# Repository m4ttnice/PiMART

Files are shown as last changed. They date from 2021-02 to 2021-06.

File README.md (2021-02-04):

# PiMART

## Introducción
Proyecto del equipo MART para la temporada 2020/2021 de Formula Student. Se pretende diseñar un sistema de telemetría basado en una Rasberry-Pi.

## Conceptos previos

El sistema debe poseer las siguientes características, ordenadas por prioridad:

1. [x] **RTC** (ds3231) para el RPI. La raspberry no tiene integrado reloj del sistema, para sistemas "aislados" se necesita añadir uno para tener un reloj sincronizado (dato indispensable para un sistema de telemetría). Utiliza bus i2c (0x68)
1. [x] Bus **i2c** en el **RPI** (pruebas con RTC (ds3231 0x68) y IMU (mpu6050 0x69))
1. [ ] (**WIP**) **i2c** para **C/C++** en la RPI (pruebas con RTC (ds3231) y IMU (mpu6050))
1. [ ] Capacidad de recepción/transmisión mediante bus **CAN**, para comunicación con la **ECU**.
1. [ ] **GPS** + **IMU** (proporcionados por TORSA) (DETERMINAR **MODELO y LIBRERÍAS** A UTILIZAR) (con un enlace al **datasheet** basta por ahora)
1. [ ] **RPI** definitiva (proporcionados por TORSA) (DETERMINAR **MODELO, SO y CARACTERÍSTICAS** A UTILIZAR)
1. [ ] Almacenamiento de datos recibidos por CAN desde ECU.
1. [ ] Leer, en la RPI, el estado de los *botones del volante* (18), se pueden usar 2 opciones:
    - **Lectura directa**: se cablea cada interruptor a un pin **GPIO** o a una entrada de **multiplexor** y este a GPIO (en ppio más simple en SOFTWARE, más complicado en HARWARE [ **MUCHOS** cables desde el volante al RPI])
    - **Lectura indirecta**: se coloca un microcontrolador en el volante el cuál lee el estado de los botones y lo comunica al RPI mediante un protocolo de comunicacion (pej. I2C, CAN , SPI) (excluyendo los problemas impícitos al protocolo de comunicaciones[distancia max del bus, compatibilidad del sw], esta opcion puede ser la más sencilla de implementar y permite un mayor grado de control)
1. [ ] Procesamiento del estado de los botones,en el RPI. Es decir ejecutar la acción de cada botón pulsado (SET MAX RPM [CAN], CHANGE DASHBOARD [SCREEN], START SAVE DATA [RPI], etc)
1. [ ] **GPS** establecer comunicacion con la placa + almacenar los datos
1. [ ] **IMU** establecer comunicación + procesar/recoger los datos provenientes de la unidad inercial
1. [ ] Pruebas de recepcion de datos a la vel. de muestreo definida
1. [ ] Pruebas de la pantalla. Envio de datos RAW 
1. [ ] Sensor de temperatura **IR** + **Distancia Laser** para las ruedas [x4]. Diseño y pruebas de prototipo.
1. [ ] Vúmetro
1. [ ] Comunicación de los 4 sensores con el RPI. En principio este sensor utiliza bus i2c (ver direcciones , posible necesite multiplexor ó otro método de comunicacion [**VER**])
    - De utilizar bus i2c HAY que utilizar **i2c diferencial** (esta en un entorno RUIDOSO y la distancia del bus es considerable)
1. [ ] Diseño del **GUI** definitivo

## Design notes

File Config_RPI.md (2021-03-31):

# Configurar RPI
https://github.com/dwyl/iot-decibel-meter/issues/3
https://user-images.githubusercontent.com/11833296/30482877-af3015fc-9a1c-11e7-9b65-a75c1b0a1f0d.png

RPI PinOUT

En este documento, se va a recoger todo lo relacionado a la configuracion de la Raspberry Pi (RPI a partir de ahora). En esta guia se ordenara de forma consecutiva todos los pasos a seguir para poner a punto la RPI con todo lo **NO** relacionado directamente con el programa principal.
Es decir, cosas como, la instalacion del sistema operativo, la configuracion de este, GPIO's, librerias de terceros, etc.

**¡¡¡ATENCION!!! Esta guia y hasta que no se indique lo contrario, es únicamente para la configuracion de RPI de pruebas y NO para la configuración DEFINITIVA**

## Prerequisitos

  ### Hardware (pre-requisitos)  
  
**WIP**
    
  ### Software (pre-requisitos)
  
**WIP**
  
## SO

  ### Instalacion
  ### Configurar SO
  ### Modificaciones
  
**WIP**
    
  ### Configuracion
  
**WIP**

## Software

  ### Paquetes instalados
  ### Librerias terceros
**WIP**  

## I2C: [alpha]
  ### Primeros pasos
  Habilitar el bus i2c en la RPI (por defecto viene deshabilitado)
  1. Abrir Terminal de la RPI
    
  1. Ejecutar la siguiente línea de comandos `sudo raspi-config` para abrir la configuracion de la RPI. Se abre una pantalla como la siguiente
  
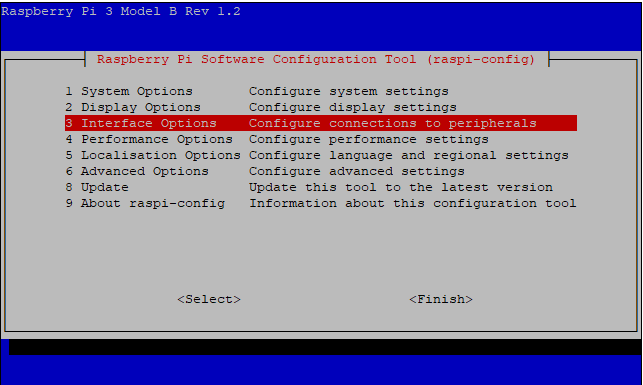
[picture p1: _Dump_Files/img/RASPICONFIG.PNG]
Raspi-Config

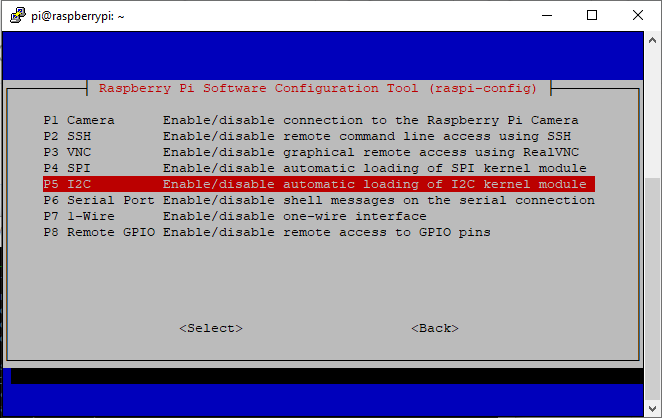
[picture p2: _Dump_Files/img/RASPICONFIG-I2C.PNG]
I2C

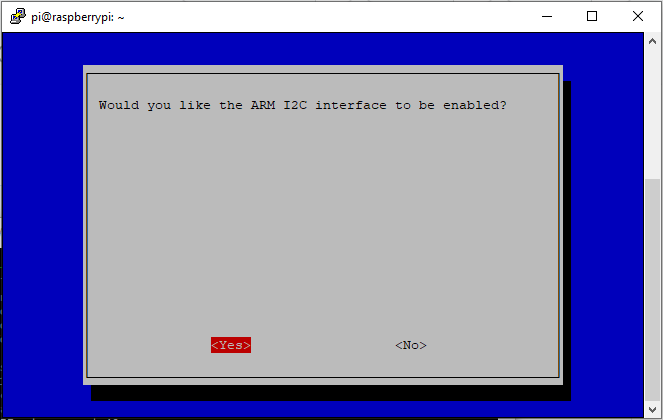
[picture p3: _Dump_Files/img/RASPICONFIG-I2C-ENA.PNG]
I2C-ENA
        
   
  1. Installar las herramientas de i2c para el SO. `sudo apt-get update` luego `sudo apt-get install i2c-tools`
    
  1. Para comprobar el resultado ejecutar `sudo i2cdetect -y 1` en caso de utilizar el bus i2c0 `sudo i2cdetect -y 0` (hay que habilitarlo) 
  
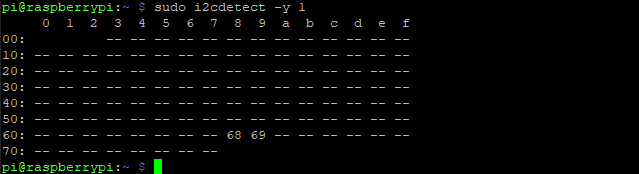
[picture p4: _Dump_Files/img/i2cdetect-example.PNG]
Addresses


  1. Lo que nos responde con las direcciones detectadas en el bus i2c1. En este caso 0x68 (RTC) y 0x69 (MPU6050)
Indicando el correcto funcionamiento del bus. 

**NOTA**: puede responder con otras direcciones o incluso con ninguna(de no tener ningun dispositivo i2c conectado.)

## RTC: ds3231 (i2c) [alpha]
  Para conectar el RTC (real time clock) a la RPI se procede de la siguiente forma:
  ### Configurar el SO para que detecte el reloj
   
   1. Seguir los pasos de habilitacion del bus i2c (si no se ha realizado ya)
    
   1. Verificar la deteccion en la RPI del RTC:
        `sudo i2cdetect -y 1`
        
Addresses
   
   1. Nos responde con la dirección 0x68 (entre otros), lo cual indica que el RTC y la RPI estan conectados.
   
   1. Se carga el modulo RTC en el kernel del sistema
    `sudo modprobe rtc-ds1307`
    
   1. Se abre un bash con privilegios de superuser
    `sudo bash`
    
   1. `echo ds1307 0x68 > /sys/class/i2c-adapter/i2c-1/newdevice`
   
   1.     `exit`
        
   1 Ya añadido el módulo se puede consultar la hora almacenada en el RTC mediante el comando 
    `sudo hwclock -r`
  
  ### Poner en hora el RTC
  Esto solo se realizara una vez al inicializar el RTC por primera vez o cuando el RTC no tenga la hora correcta
    
    1. Se ha de disponer de conexion a internet
    
    1.El RTC debe estar correctamente conectado y configurado
    
    1.Ejecutar en el terminal el siguiente comando `date` esto actualiza la hora del sistema desde el servidor (este punto suele ser automático al realizar la conexion a internet) y la muestra por el terminal.
    
    1. Con la hora del sistema correctamente sincronizada se escribe en el terminal `sudo hwclock -w` para escribir en el RTC la hora correcta.
    
    1. Se comprueba que la hora almacenada en el RTC sea la adecuada `sudo hwclock -r`
    
   ### Hacer que la RPI lea la hora del RTC al inicializar
   Esto sirve para que la RPI (sin conexion a internet) acceda a la hora del RTC al arrancar el SO. Para ello se realizan los siguientes pasos:
   
   1. Se edita (con nano) el archivo que carga los dispositivos de la RPI al arrancar el sistema
   `sudo nano /etc/modules`
   y se añade la linea `"rtc-ds1307"` al final del archivo. Salimos y guardamos pulsando `Ctrl + O` `Ctrl + X`.
   
   1. A continuación se añade el RTC como reloj del sistema en rc.local
   `sudo nano /etc/rc.local`
   se añade `"echo ds1307 0x68 > /sys/class/i2c-adapter/i2c-1/new_device"`
   `"sudo hwclock"`
   `"date"`
   antes de **exit 0**. Salimos y guardamos pulsando `Ctrl + O` `Ctrl + X`.
   
   1. Se reinicia la máquina `sudo shutdown -r now`
   
   1. Al cargar se puede ver la hora del sistema con `date`
   
### Instalar y Configurar el bus Can (Libreria Can-utils)
    Referencia : https://www.raspberrypi.org/forums/viewtopic.php?t=141052 
    MCP2515 : https://ww1.microchip.com/downloads/en/DeviceDoc/MCP2515-Stand-Alone-CAN-Controller-with-SPI-20001801J.pdf

## AD1115(conversor analogico-digital) [alpha]
https://www.ti.com/lit/ds/symlink/ads1113.pdf?ts=1617192483667&ref_url=https%253A%252F%252Fwww.google.com%252F

## IMU: MPU6050 (i2c) [alpha]

## **WIP**

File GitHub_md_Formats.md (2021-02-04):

## ////////TITLES///////////
# Title 1

## Title2

## //////// TEXT FORMAT////////

**Strong/Bold**
_this is italic_
_**MIX**example_**is**here

to ~~corect~~ **correct**, it's a good practice to sow the previous error

## ////////// LIST TABLES ////////////////

LIST UNORDERED:
* Item 1, no indent
  * Item2, indented
    * subItem21, 2 indent 
  * Item3,etc
  
LIST ORDERED:
1. Item1
    1. subItem11
    1. subItem12
1.  Item2

TABLE:
HEADER1|HEADER2
-------|-------
cell11 |cell21|
cell12 |cell22|

TASK LIST:
- [x] @mentions, #refs, [links](), **formatting**, and <del>tags</del> supported
- [x] list syntax required (any unordered or ordered list supported)
- [x] this is a complete item
- [ ] this is an incomplete item
 
## ///////////////// LINKS IMG ////////////////////////// 
 
 to add an URL link, it's can be done like this:
 https://github.com/m4ttnice/PiMART.git
 OR a more custom option like
 [PiMART repo](https://github.com/m4ttnice/PiMART.git)
 
 AND add images:
 
   
 
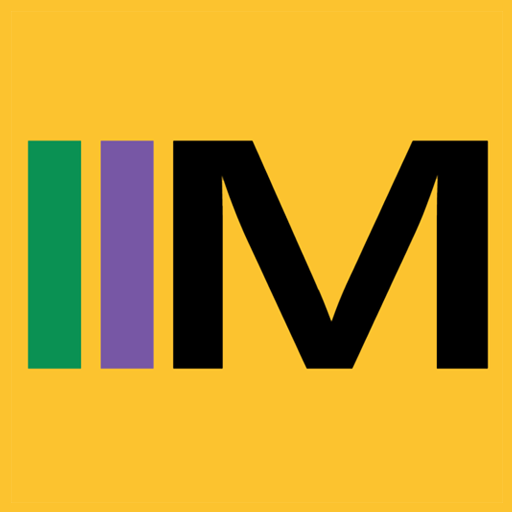
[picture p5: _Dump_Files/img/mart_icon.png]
MART Logo


## /////////////////// PAGE FORMAT /////////////////////
you can split by lines

---
A comment can be put
>comments (**by**)

or a mention using `@` with a username  @m4ttnice

Or an inline code lie this
`<addr>` element here instead.

if you want to put example codes:
C++ (you can choose the language for Highligthed code format)

```cpp
#include <iostream>

int main ()
	{
		char n ;
			std::cout << "Hello World";
			std::cin >> n;
		while ( n!= 'q')
		{std::cin >> n;}
			return 0;
	}
  ```

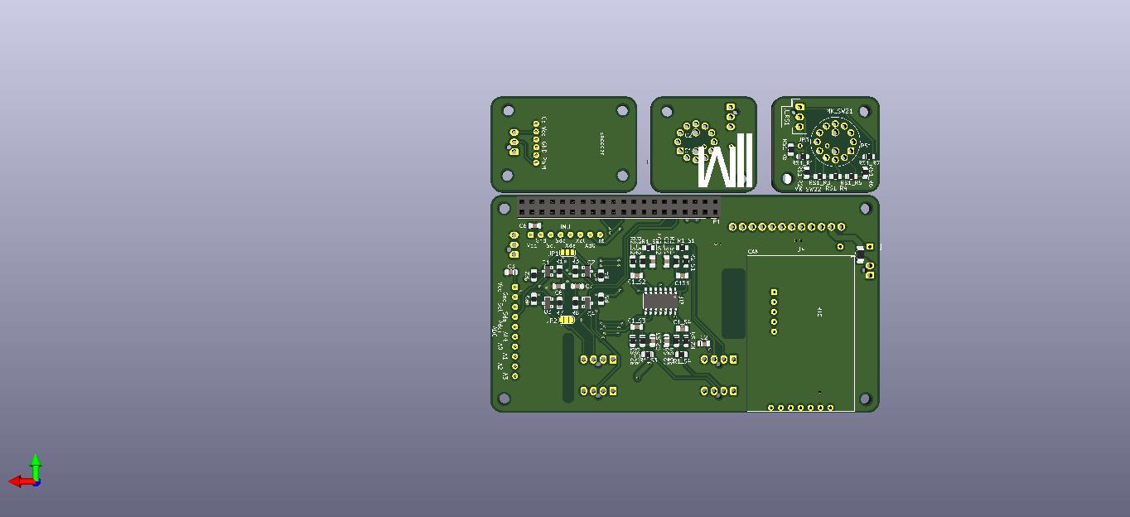
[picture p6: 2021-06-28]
KiCad/PI_MARTLOgger_Back.jpg

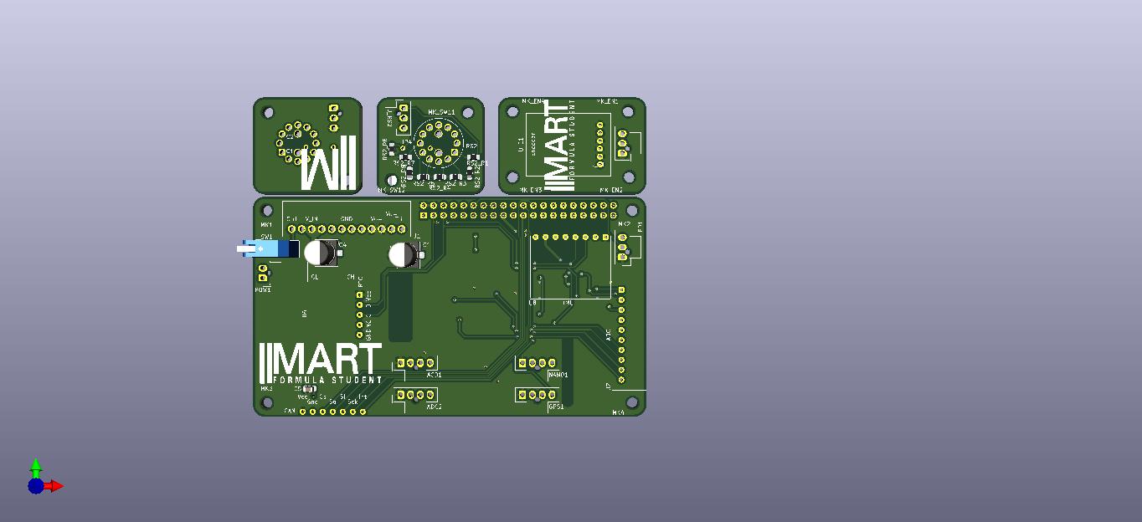
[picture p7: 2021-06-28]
KiCad/PI_MARTLOgger_Front.jpg

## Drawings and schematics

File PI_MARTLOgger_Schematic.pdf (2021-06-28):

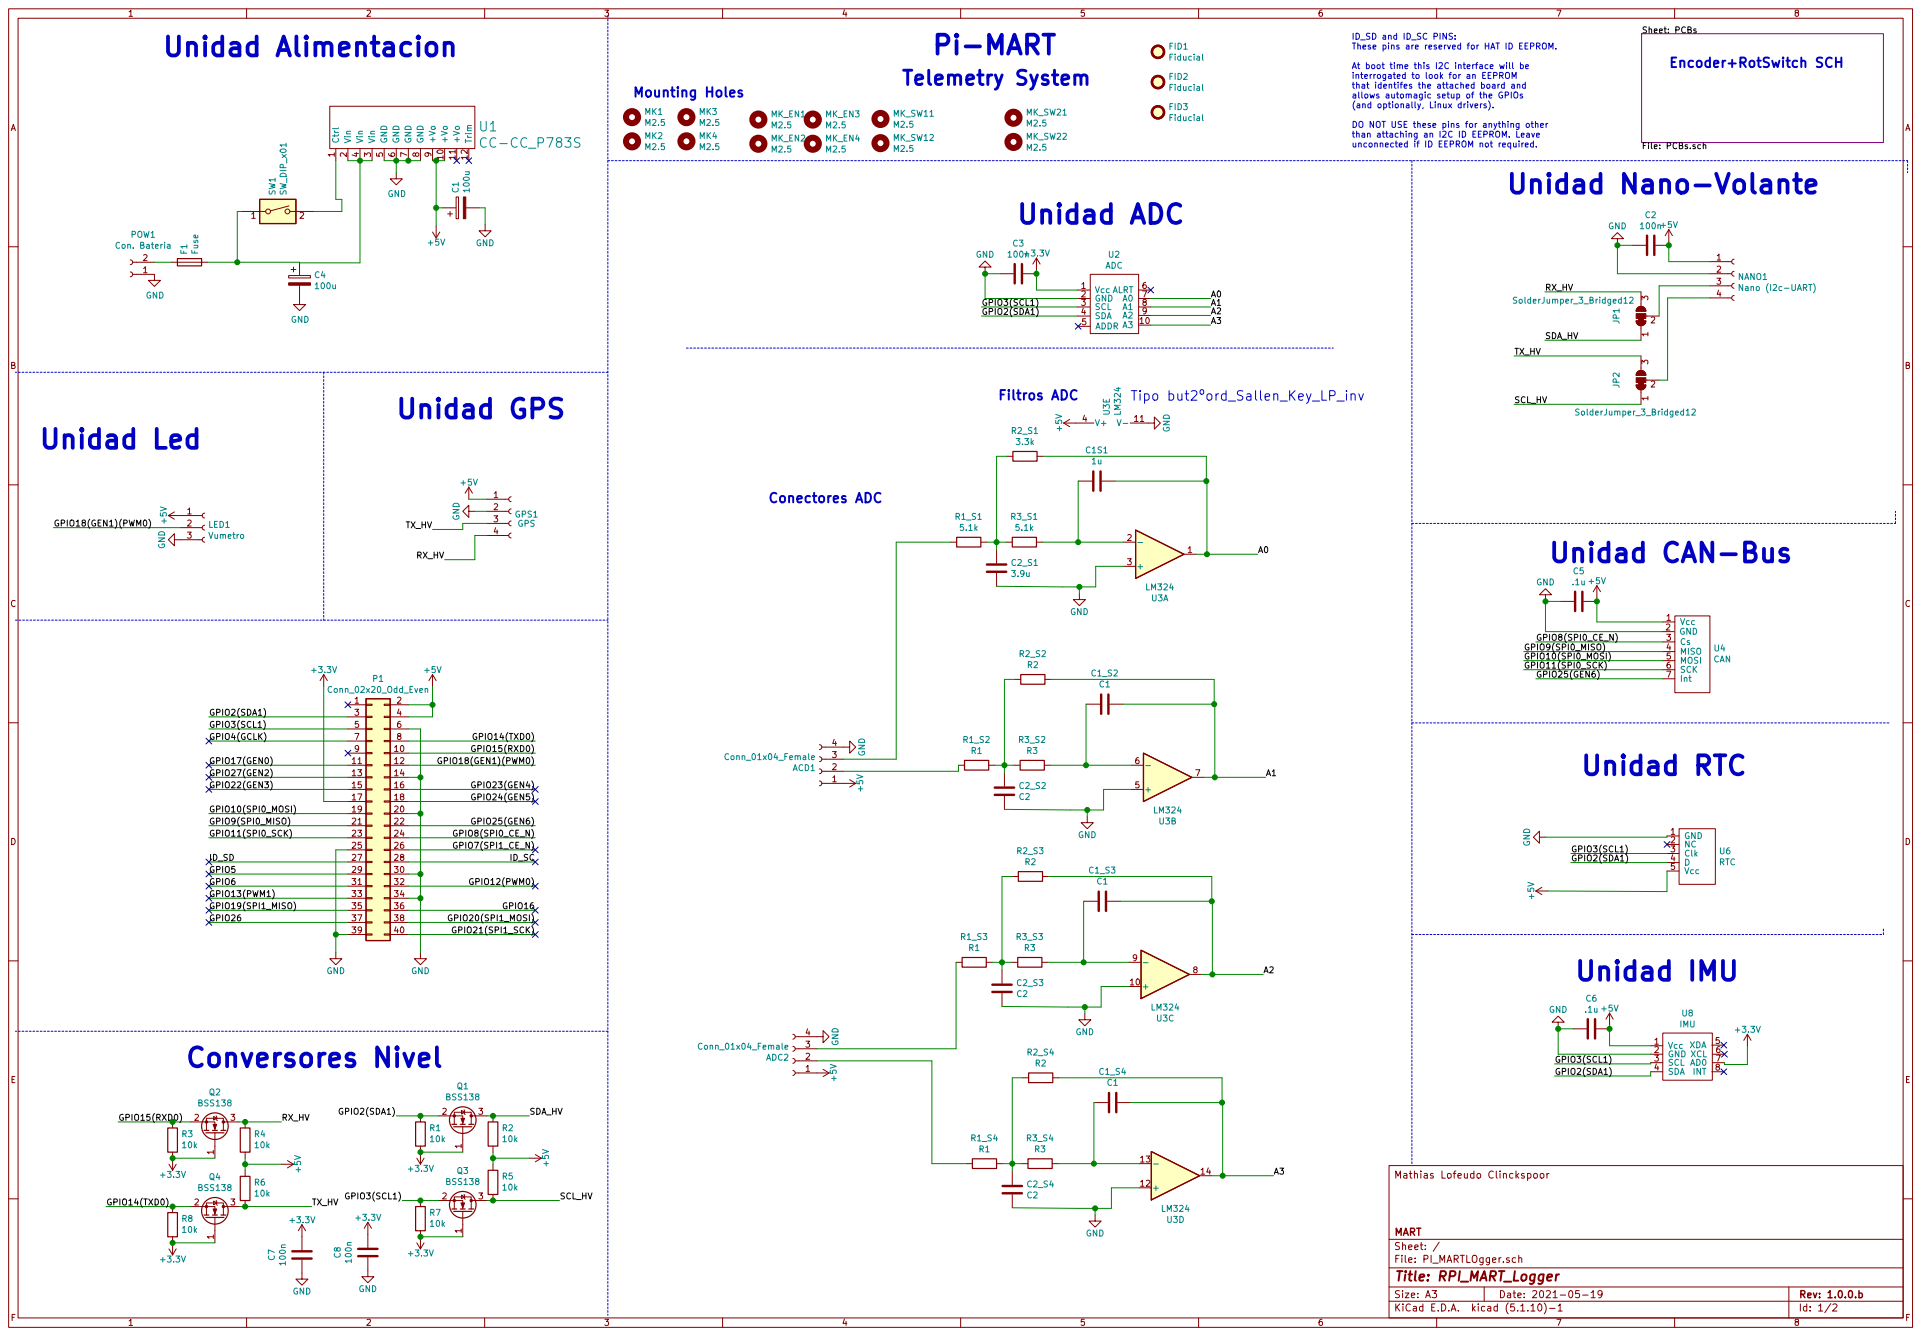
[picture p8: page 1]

ID_SD and ID_SC PINS: These pins are reserved for HAT ID EEPROM. At boot time this I2C interface will be

Sheet: PCBs File: PCBs.sch
Encoder+RotSwitch SCH

interrogated to look for an EEPROM
that identifes the attached board and
allows automagic setup of the GPIOs
(and optionally, Linux drivers).

DO NOT USE these pins for anything other
than attaching an I2C ID EEPROM. Leave
unconnected if ID EEPROM not required.

File: PI_MARTLOgger.sch Sheet: / MART Mathias Lofeudo Clinckspoor

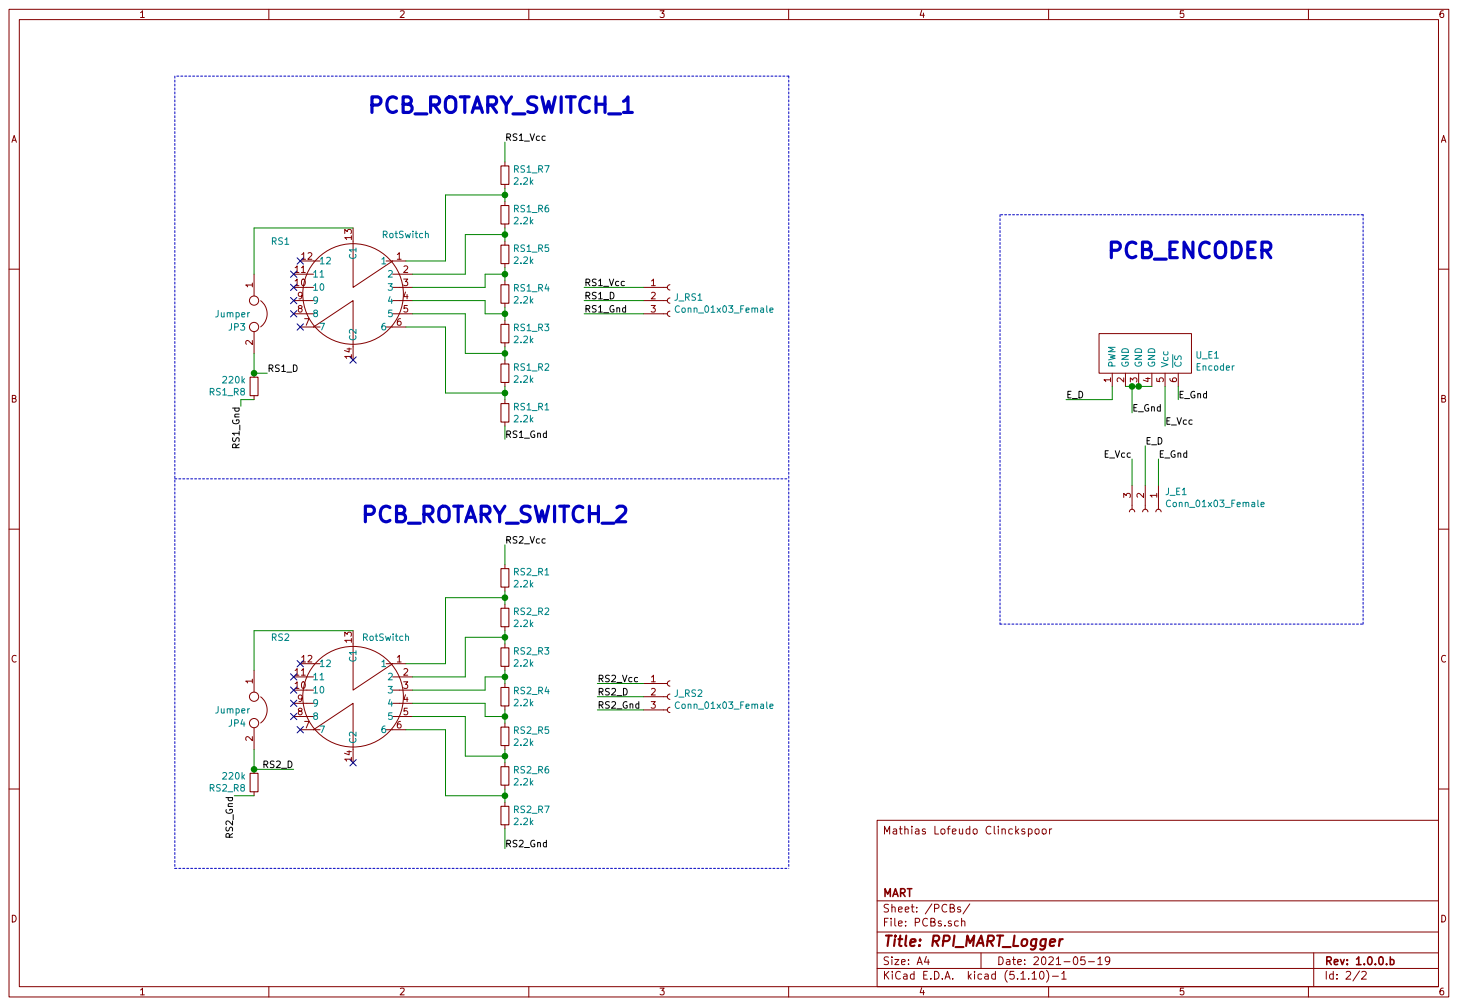
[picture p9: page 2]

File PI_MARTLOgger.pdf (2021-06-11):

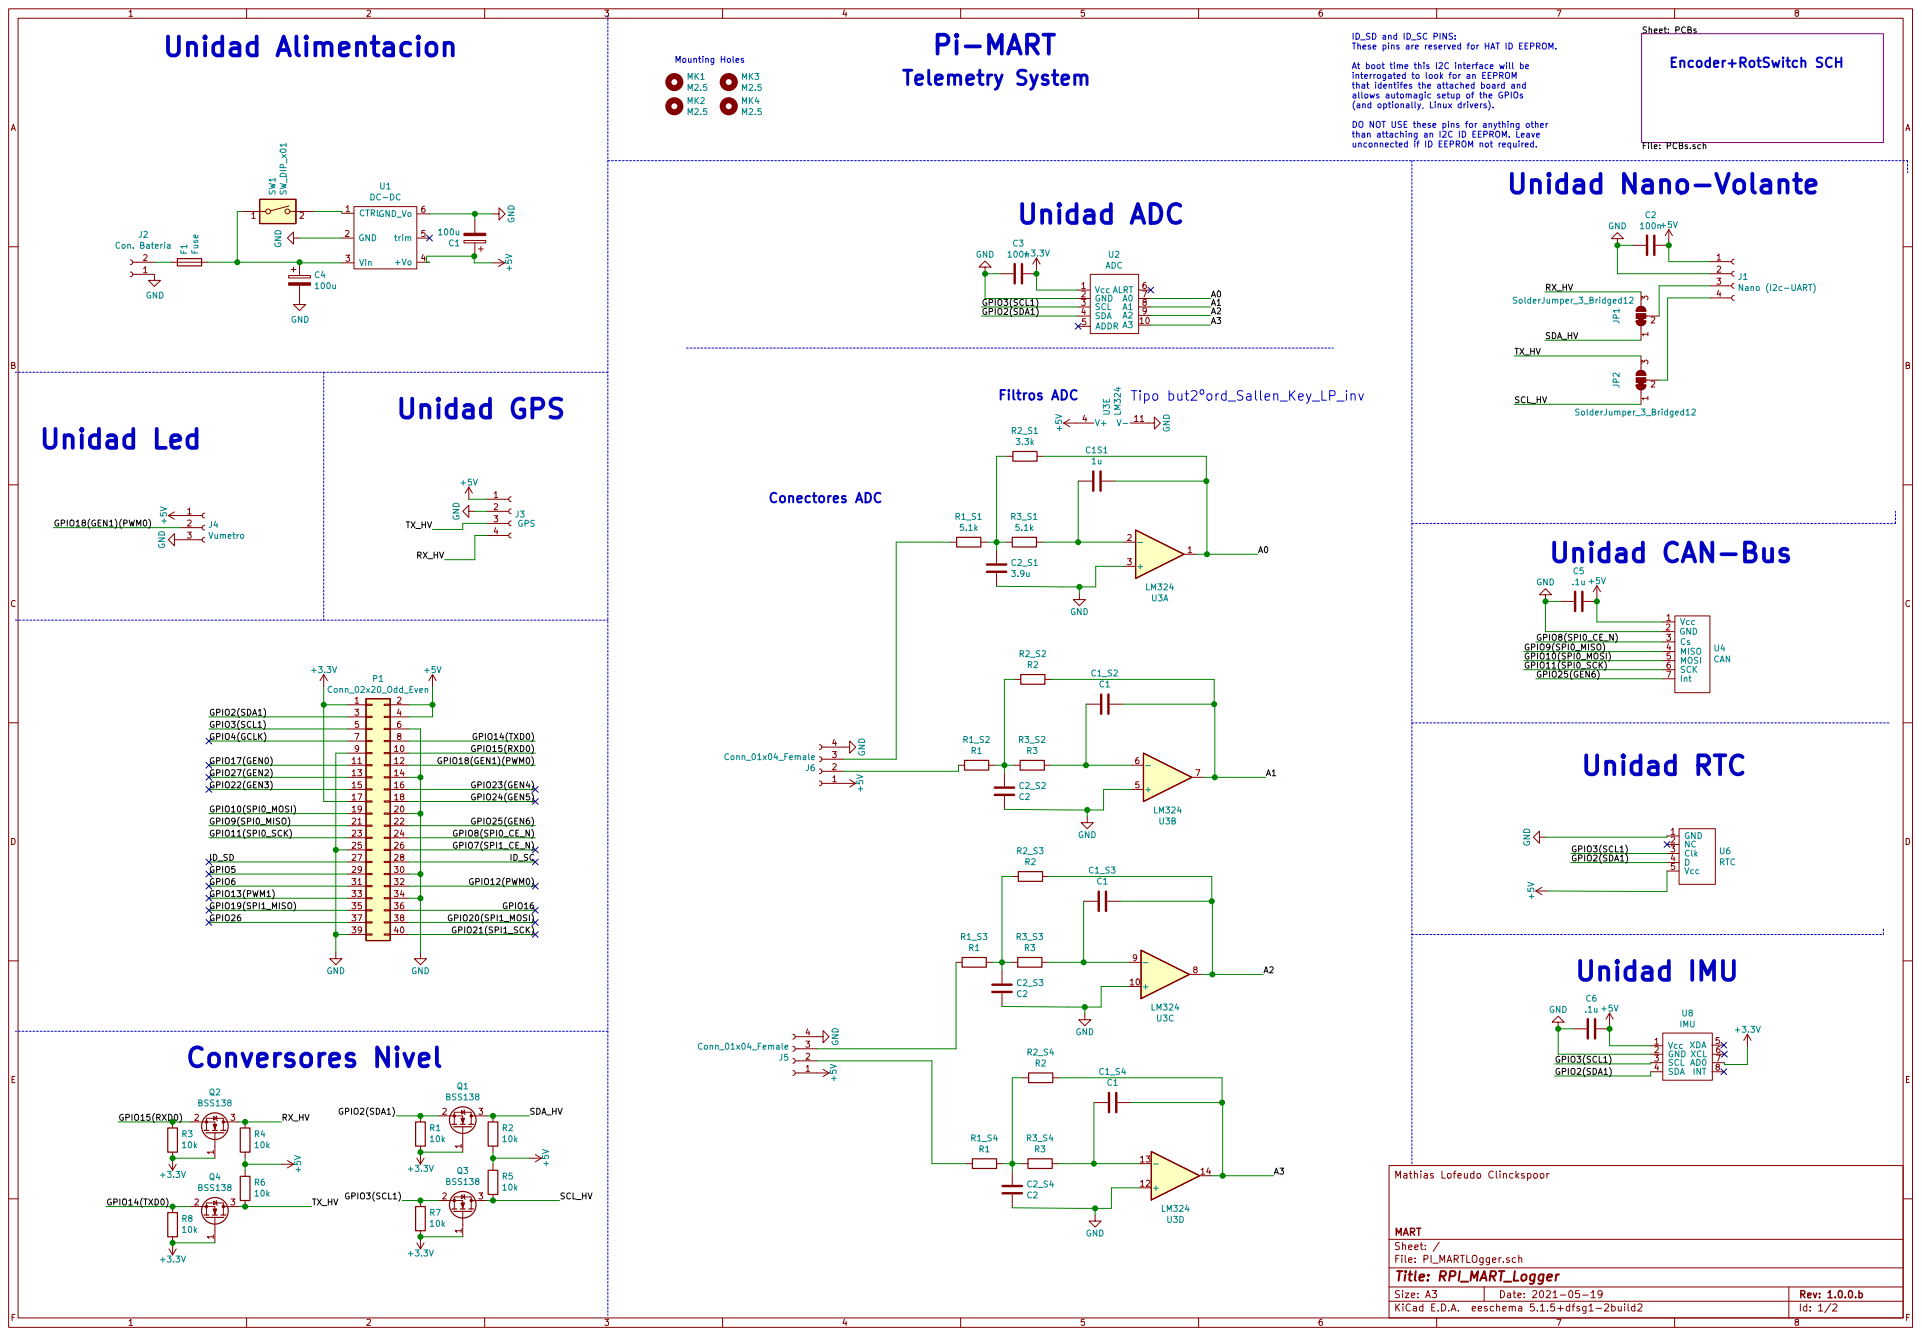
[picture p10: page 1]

Sheet: PCBs File: PCBs.sch MK4 M2.5

ID_SD and ID_SC PINS: These pins are reserved for HAT ID EEPROM. At boot time this I2C interface will be

interrogated to look for an EEPROM
that identifes the attached board and
allows automagic setup of the GPIOs
(and optionally, Linux drivers).

DO NOT USE these pins for anything other
than attaching an I2C ID EEPROM. Leave
unconnected if ID EEPROM not required.

15 | 16 18 20
17

File: PI_MARTLOgger.sch Sheet: / MART Mathias Lofeudo Clinckspoor

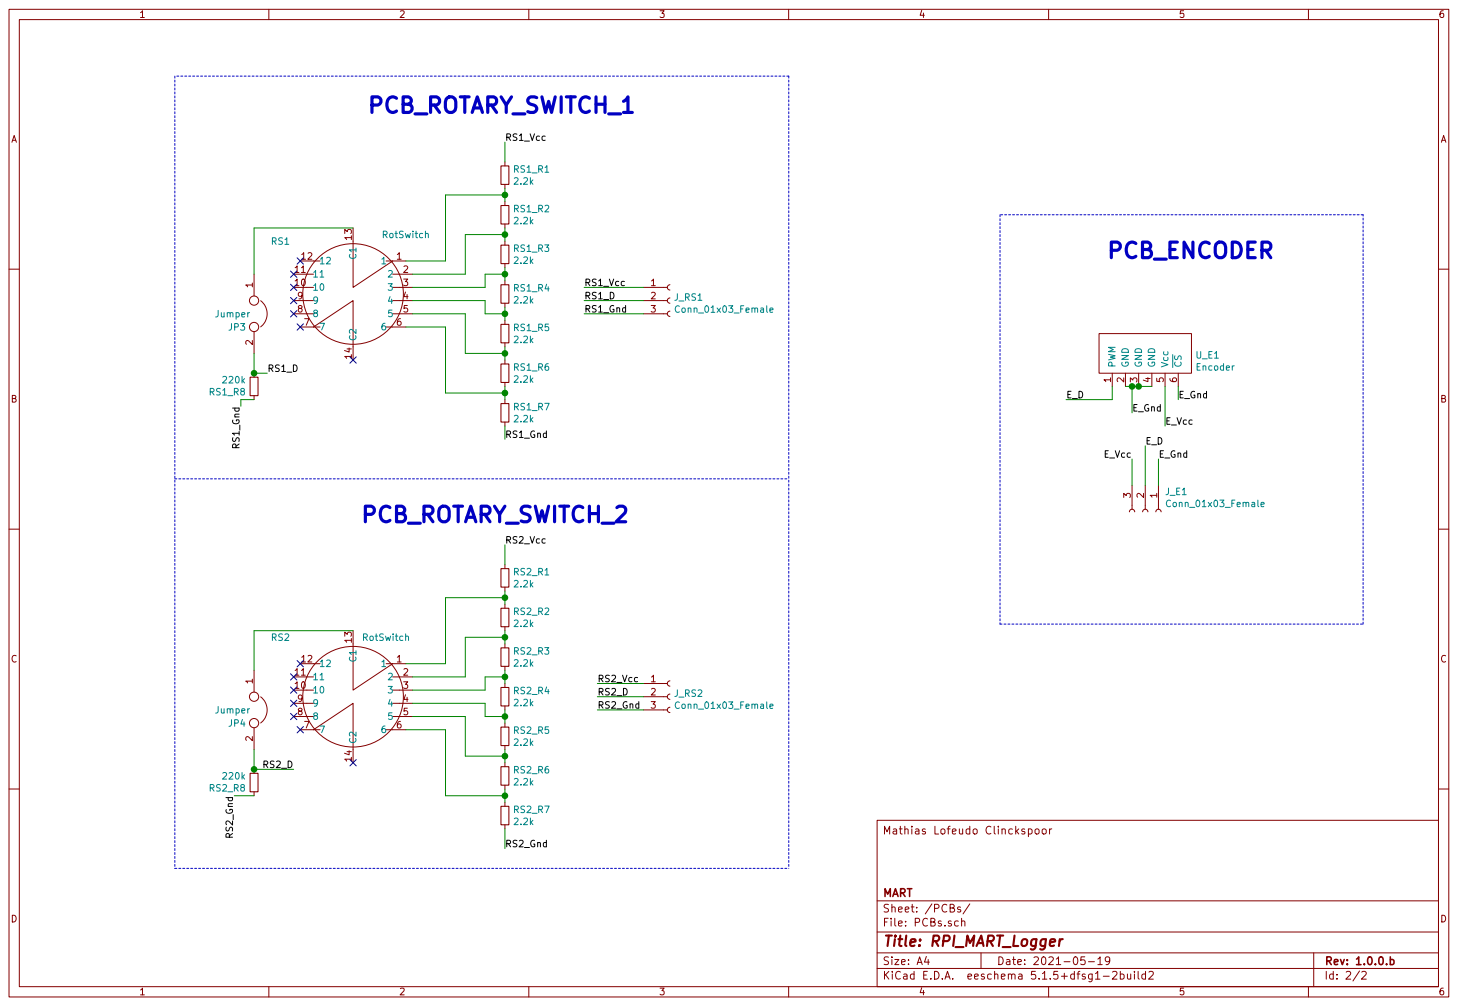
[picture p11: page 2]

Id: 2/2 Title: RPI_MART_Logger File: PCBs.sch Sheet: /PCBs/ MART Mathias Lofeudo Clinckspoor RS2_R5

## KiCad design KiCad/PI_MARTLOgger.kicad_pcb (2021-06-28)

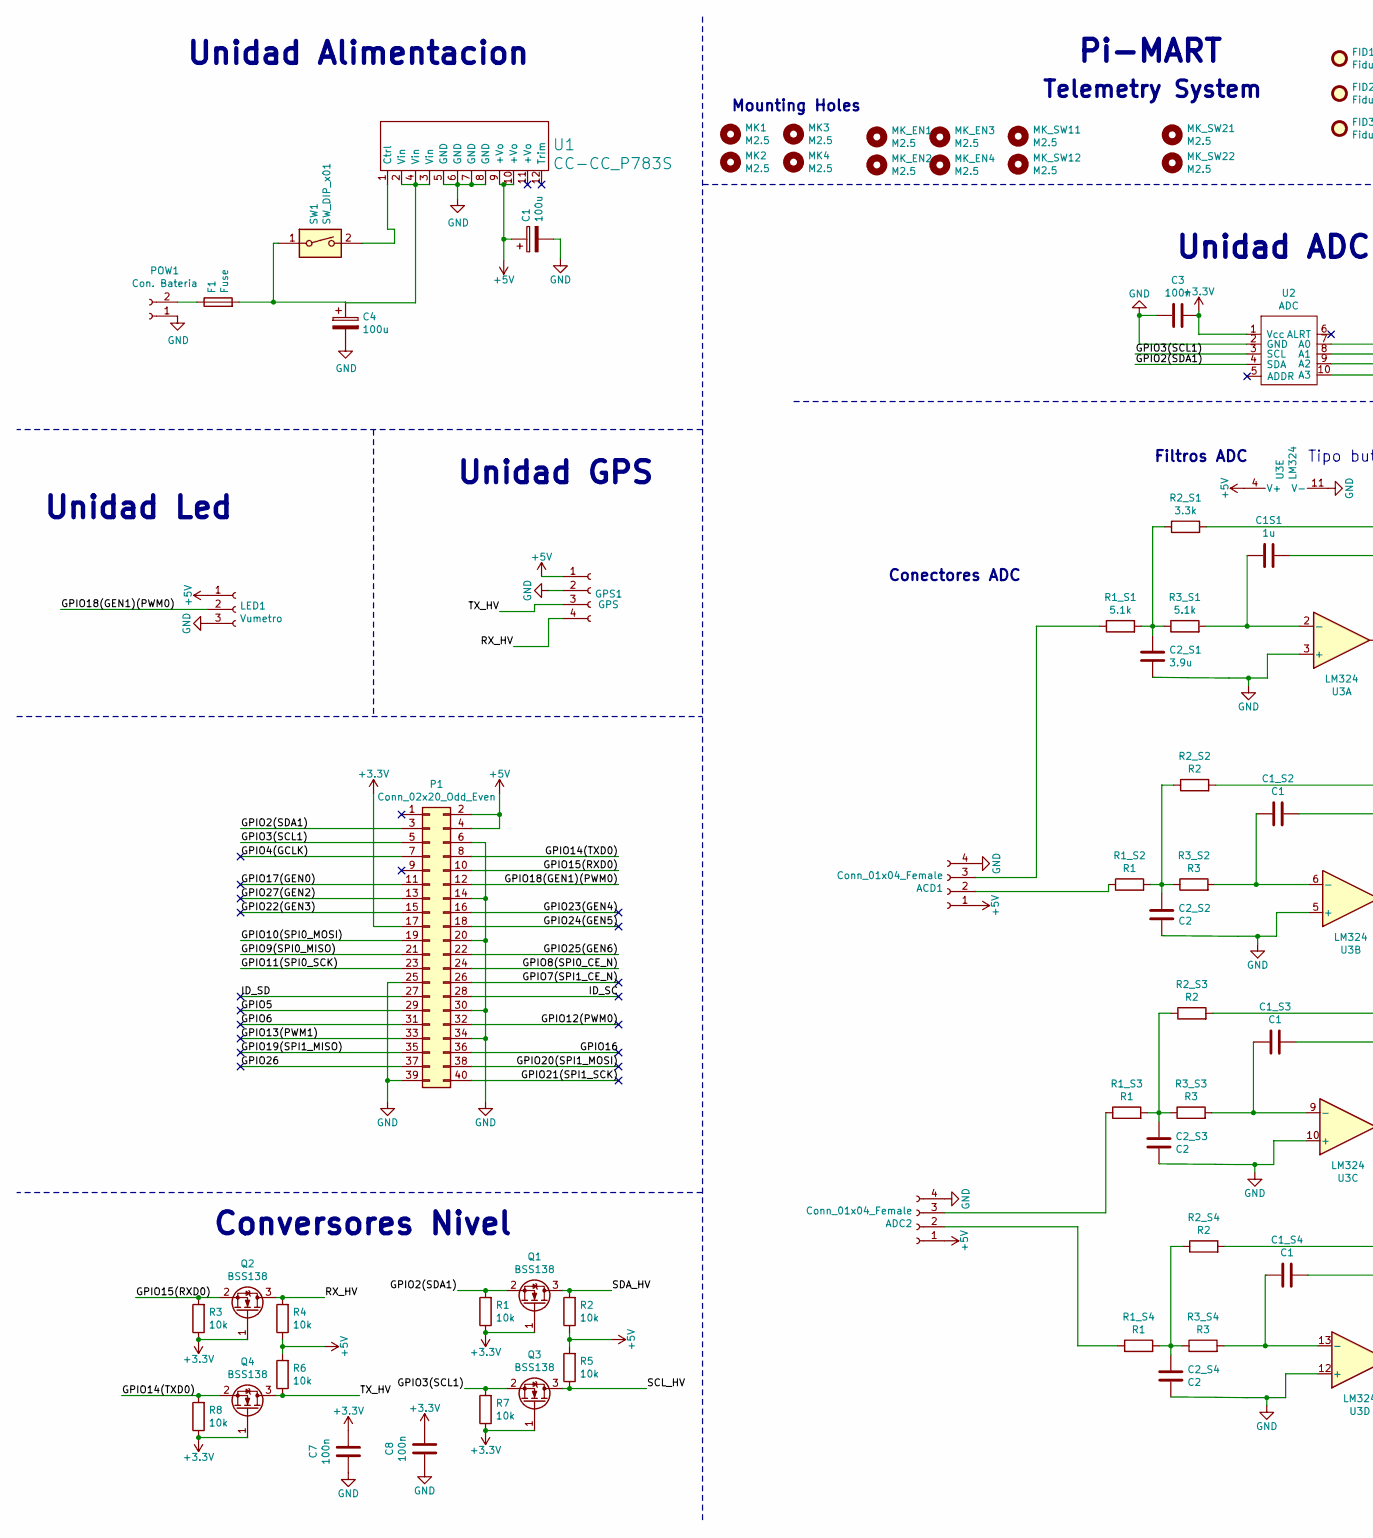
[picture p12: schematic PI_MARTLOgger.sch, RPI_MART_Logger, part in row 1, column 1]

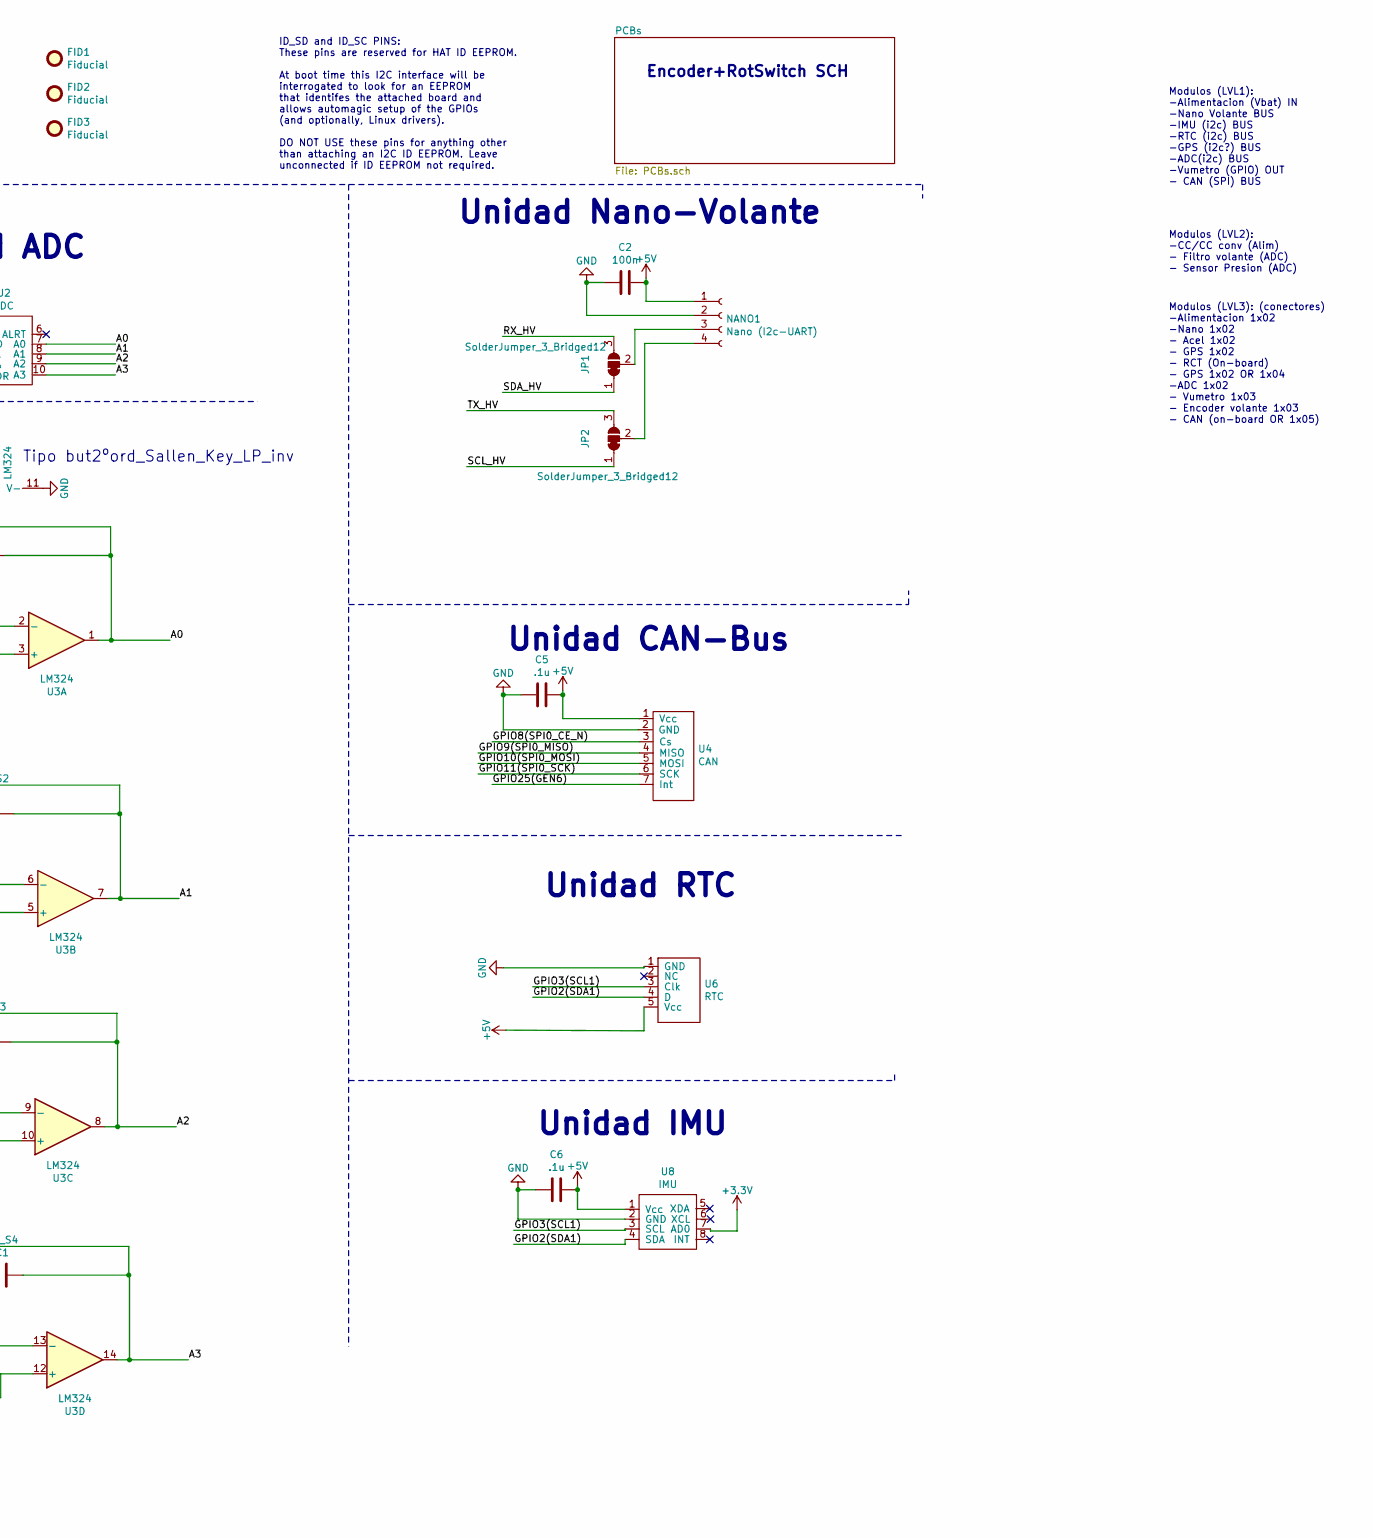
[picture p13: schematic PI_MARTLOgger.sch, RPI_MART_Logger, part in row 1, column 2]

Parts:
ACD1: Conn_01x04_Female; Molex_Nano-Fit_105309-xx04_1x04_P2.50mm_Vertical
ADC2: Conn_01x04_Female; Molex_Nano-Fit_105309-xx04_1x04_P2.50mm_Vertical
C1, C4: 100u; CP_Elec_6.3x7.7
C1S1: 1u; C_0805_2012Metric_Pad1.18x1.45mm_HandSolder
C1_S2, C1_S3, C1_S4: C1; C_0805_2012Metric_Pad1.18x1.45mm_HandSolder
C2, C3, C7, C8: 100n; C_0805_2012Metric_Pad1.18x1.45mm_HandSolder
C2_S1: 3.9u; C_0805_2012Metric_Pad1.18x1.45mm_HandSolder
C2_S2, C2_S3, C2_S4: C2; C_0805_2012Metric_Pad1.18x1.45mm_HandSolder
C5, C6: .1u; C_0805_2012Metric_Pad1.18x1.45mm_HandSolder
F1: Fuse; Fuse_1206_3216Metric_Pad1.42x1.75mm_HandSolder
FID1, FID2, FID3: Fiducial; Fiducial_0.5mm_Mask1.5mm
GPS1: GPS; Molex_Nano-Fit_105310-xx08_2x04_P2.50mm_Vertical
JP1, JP2: SolderJumper_3_Bridged12; SolderJumper-3_P1.3mm_Bridged12_RoundedPad1.0x1.5mm
LED1: Vumetro; Molex_Nano-Fit_105313-xx03_1x03_P2.50mm_Horizontal
MK1, MK2, MK3, MK4: M2.5; MountingHole_2.7mm_M2.5
MK_EN1, MK_EN2, MK_EN3, MK_EN4: M2.5; MountingHole_2.7mm_M2.5
MK_SW11, MK_SW12, MK_SW21, MK_SW22: M2.5; MountingHole_2.7mm_M2.5
NANO1: Nano (I2c-UART); Molex_Nano-Fit_105313-xx04_1x04_P2.50mm_Horizontal
P1: Conn_02x20_Odd_Even; PinSocket_2x20_P2.54mm_Vertical
POW1: Con. Bateria; Molex_Nano-Fit_105313-xx02_1x02_P2.50mm_Horizontal
Q1, Q2, Q3, Q4: BSS138; SOT-23
R1, R2, R3, R4, R5, R6, R7, R8: 10k; R_0805_2012Metric_Pad1.20x1.40mm_HandSolder
R1_S1, R3_S1: 5.1k; R_0805_2012Metric_Pad1.20x1.40mm_HandSolder
R1_S2, R1_S3, R1_S4: R1; R_0805_2012Metric_Pad1.20x1.40mm_HandSolder
R2_S1: 3.3k; R_0805_2012Metric_Pad1.20x1.40mm_HandSolder
R2_S2, R2_S3, R2_S4: R2; R_0805_2012Metric_Pad1.20x1.40mm_HandSolder
R3_S2, R3_S3, R3_S4: R3; R_0805_2012Metric_Pad1.20x1.40mm_HandSolder
SW1: SW_DIP_x01; SW_DIP_SPSTx01_Piano_10.8x4.1mm_W7.62mm_P2.54mm
U1: CC-CC_P783S; CC-CC_PT83-S
U2: ADC
U3: LM324; SOIC-14_3.9x8.7mm_P1.27mm
U4: CAN
U6: RTC
U8: IMU

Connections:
+3V3: C3.1, C7.1, C8.1, P1.17, Q1.1 (G), Q2.1 (G), Q3.1 (G), Q4.1 (G), R1.1, R3.1, R7.1, R8.1, U2.1 (Vcc), U8.7 (AD0)
+5V: ACD1.1, ADC2.1, C1.1, C2.1, C5.1, C6.1, GPS1.1, LED1.1, NANO1.1, P1.2, P1.4, R2.1, R4.1, R5.2, R6.2, U1.9 (+Vo), U1.10 (+Vo), U3.4 (V+), U4.1 (Vcc), U6.5 (Vcc), U8.1 (Vcc)
/A0: C1S1.2, R2_S1.2, U2.7 (A0), U3.1
/A1: C1_S2.2, R2_S2.2, U2.8 (A1), U3.7
/A2: C1_S3.2, R2_S3.2, U2.9 (A2), U3.8
/A3: C1_S4.2, R2_S4.2, U2.10 (A3), U3.14
/GPIO2(SDA1): P1.3, Q1.2 (S), R1.2, U2.4 (SDA), U6.4 (D), U8.4 (SDA)
/GPIO3(SCL1): P1.5, Q3.2 (S), R7.2, U2.3 (SCL), U6.3 (Clk), U8.3 (SCL)
/GPIO4(GCLK): P1.7
/GPIO5: P1.29
/GPIO6: P1.31
/GPIO7(SPI1_CE_N): P1.26
/GPIO8(SPI0_CE_N): P1.24, U4.3 (Cs)
/GPIO9(SPI0_MISO): P1.21, U4.4 (MISO)
/GPIO10(SPI0_MOSI): P1.19, U4.5 (MOSI)
/GPIO11(SPI0_SCK): P1.23, U4.6 (SCK)
/GPIO12(PWM0): P1.32
/GPIO13(PWM1): P1.33
/GPIO14(TXD0): P1.8, Q4.2 (S), R8.2
/GPIO15(RXD0): P1.10, Q2.2 (S), R3.2
/GPIO16: P1.36
/GPIO17(GEN0): P1.11
/GPIO18(GEN1)(PWM0): LED1.2, P1.12
/GPIO19(SPI1_MISO): P1.35
/GPIO20(SPI1_MOSI): P1.38
/GPIO21(SPI1_SCK): P1.40
/GPIO22(GEN3): P1.15
/GPIO23(GEN4): P1.16
/GPIO24(GEN5): P1.18
/GPIO25(GEN6): P1.22, U4.7 (Int)
/GPIO26: P1.37
/GPIO27(GEN2): P1.13
/ID_SC: P1.28
/ID_SD: P1.27
/RX_HV: GPS1.4, JP1.3 (B), Q2.3 (D), R4.2
/SCL_HV: JP2.1 (A), Q3.3 (D), R5.1
/SDA_HV: JP1.1 (A), Q1.3 (D), R2.2
/TX_HV: GPS1.3, JP2.3 (B), Q4.3 (D), R6.1
GND: ACD1.4, ADC2.4, C1.2, C2.2, C2_S1.2, C2_S2.2, C2_S3.2, C2_S4.2, C3.2, C4.2, C5.2, C6.2, C7.2, C8.2, GPS1.2, LED1.3, NANO1.2, P1.6, P1.14, P1.20, P1.25, P1.30, P1.34, P1.39, POW1.1, U1.5 (GND), U1.6 (GND), U1.7 (GND), U1.8 (GND), U2.2 (GND), U3.3 (+), U3.5 (+), U3.10 (+), U3.11 (V-), U3.12 (+), U4.2 (GND), U6.1 (GND), U8.2 (GND)
unnamed: ACD1.2, R1_S2.1
unnamed: ACD1.3, R1_S1.1
unnamed: ADC2.2, R1_S4.1
unnamed: ADC2.3, R1_S3.1
unnamed: C1S1.1, R3_S1.2, U3.2 (-)
unnamed: C1_S2.1, R3_S2.2, U3.6 (-)
unnamed: C1_S3.1, R3_S3.2, U3.9 (-)
unnamed: C1_S4.1, R3_S4.2, U3.13 (-)
unnamed: C2_S1.1, R1_S1.2, R2_S1.1, R3_S1.1
unnamed: C2_S2.1, R1_S2.2, R2_S2.1, R3_S2.1
unnamed: C2_S3.1, R1_S3.2, R2_S3.1, R3_S3.1
unnamed: C2_S4.1, R1_S4.2, R2_S4.1, R3_S4.1
unnamed: C4.1, F1.2, SW1.1, U1.2 (Vin), U1.3 (Vin), U1.4 (Vin)
unnamed: F1.1, POW1.2
unnamed: JP1.2 (C), NANO1.3
unnamed: JP2.2 (C), NANO1.4
unnamed: SW1.2, U1.1 (Ctrl)

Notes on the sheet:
ID_SD and ID_SC PINS: These pins are reserved for HAT ID EEPROM. At boot time this I2C interface will be interrogated to look for an EEPROM that identifes the attached board and allows automagic setup of the GPIOs (and optionally, Linux drivers). DO NOT USE these pins for anything other than attach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
Mounting Holes
Modulos (LVL1): -Alimentacion (Vbat) IN -Nano Volante BUS -IMU (i2c) BUS -RTC (i2c) BUS -GPS (i2c?) BUS -ADC(i2c) BUS -Vumetro (GPIO) OUT - CAN (SPI) BUS
Modulos (LVL2): -CC/CC conv (Alim) - Filtro volante (ADC) - Sensor Presion (ADC)
Modulos (LVL3): (conectores) -Alimentacion 1x02 -Nano 1x02 - Acel 1x02 - GPS 1x02 - RCT (On-board) - GPS 1x02 OR 1x04 -ADC 1x02 - Vumetro 1x03 - Encoder volante 1x03 - CAN (on-board OR 1x05)
Unidad IMU
Unidad RTC
Unidad CAN-Bus
Unidad Nano-Volante
Unidad ADC
Conectores ADC
Filtros ADC
Tipo but2ºord_Sallen_Key_LP_inv
Unidad Led
Unidad GPS
Conversores Nivel
Unidad Alimentacion
Pi-MART
Telemetry System
Encoder+RotSwitch SCH

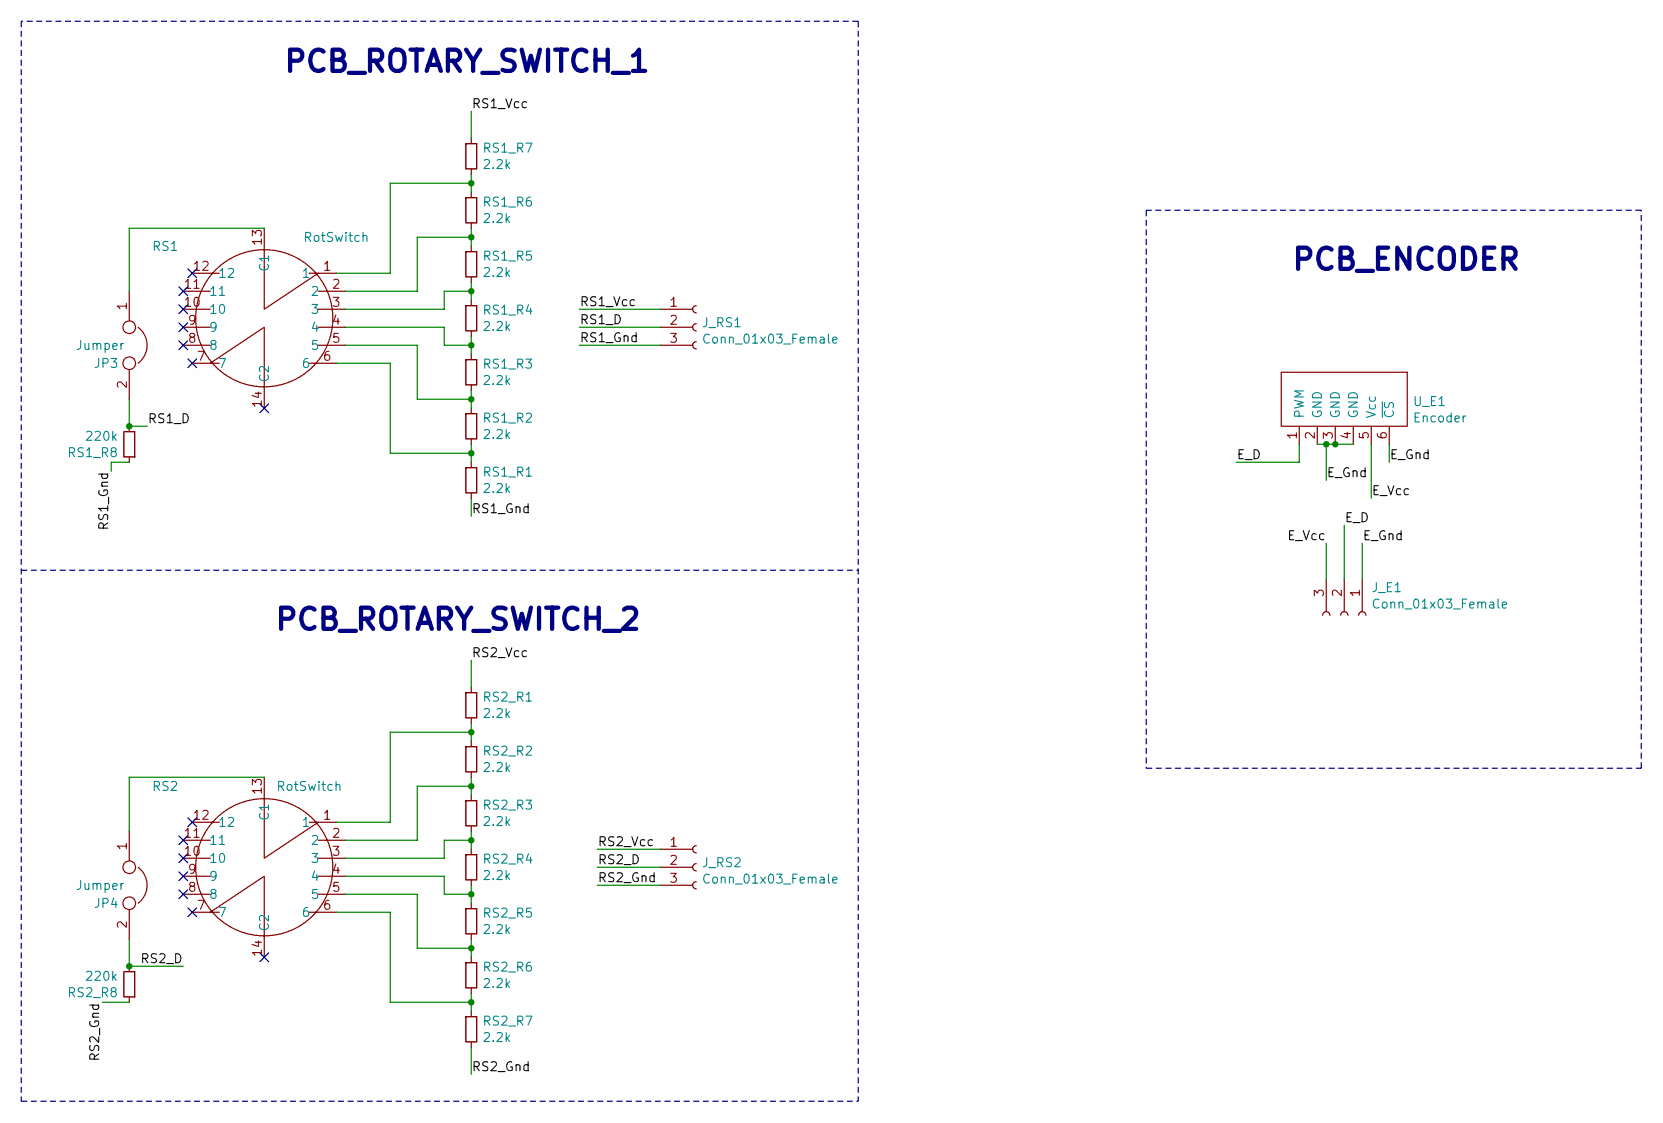
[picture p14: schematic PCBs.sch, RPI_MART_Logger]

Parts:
JP3, JP4: Jumper; Bridge_7mm
J_E1: Conn_01x03_Female; Molex_Nano-Fit_105313-xx03_1x03_P2.50mm_Horizontal
J_RS1, J_RS2: Conn_01x03_Female; Molex_Nano-Fit_105313-xx03_1x03_P2.50mm_Horizontal
RS1, RS2: RotSwitch; Rot_Switch
RS1_R1, RS1_R2, RS1_R3, RS1_R4, RS1_R5, RS1_R6, RS1_R7, RS2_R1, RS2_R2, RS2_R3, RS2_R4, RS2_R5, RS2_R6, RS2_R7: 2.2k; R_0805_2012Metric_Pad1.20x1.40mm_HandSolder
RS1_R8, RS2_R8: 220k; R_0805_2012Metric_Pad1.20x1.40mm_HandSolder
U_E1: Encoder

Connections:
/PCBs/E_D: J_E1.2, U_E1.1 (PWM)
/PCBs/E_Gnd: J_E1.1, U_E1.2 (GND), U_E1.3 (GND), U_E1.4 (GND), U_E1.6 (~CS)
/PCBs/E_Vcc: J_E1.3, U_E1.5 (Vcc)
/PCBs/RS1_D: JP3.2, J_RS1.2, RS1_R8.2
/PCBs/RS1_Gnd: J_RS1.3, RS1_R1.2, RS1_R8.1
/PCBs/RS1_Vcc: J_RS1.1, RS1_R7.1
/PCBs/RS2_D: JP4.2, J_RS2.2, RS2_R8.2
/PCBs/RS2_Gnd: J_RS2.3, RS2_R7.2, RS2_R8.1
/PCBs/RS2_Vcc: J_RS2.1, RS2_R1.1
unnamed: JP3.1, RS1.13 (C1)
unnamed: JP4.1, RS2.13 (C1)
unnamed: RS1.1, RS1_R6.1, RS1_R7.2
unnamed: RS1.2, RS1_R5.1, RS1_R6.2
unnamed: RS1.3, RS1_R4.1, RS1_R5.2
unnamed: RS1.4, RS1_R3.1, RS1_R4.2
unnamed: RS1.5, RS1_R2.1, RS1_R3.2
unnamed: RS1.6, RS1_R1.1, RS1_R2.2
unnamed: RS2.1, RS2_R1.2, RS2_R2.1
unnamed: RS2.2, RS2_R2.2, RS2_R3.1
unnamed: RS2.3, RS2_R3.2, RS2_R4.1
unnamed: RS2.4, RS2_R4.2, RS2_R5.1
unnamed: RS2.5, RS2_R5.2, RS2_R6.1
unnamed: RS2.6, RS2_R6.2, RS2_R7.1

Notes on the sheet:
PCB_ENCODER
PCB_ROTARY_SWITCH_1
PCB_ROTARY_SWITCH_2

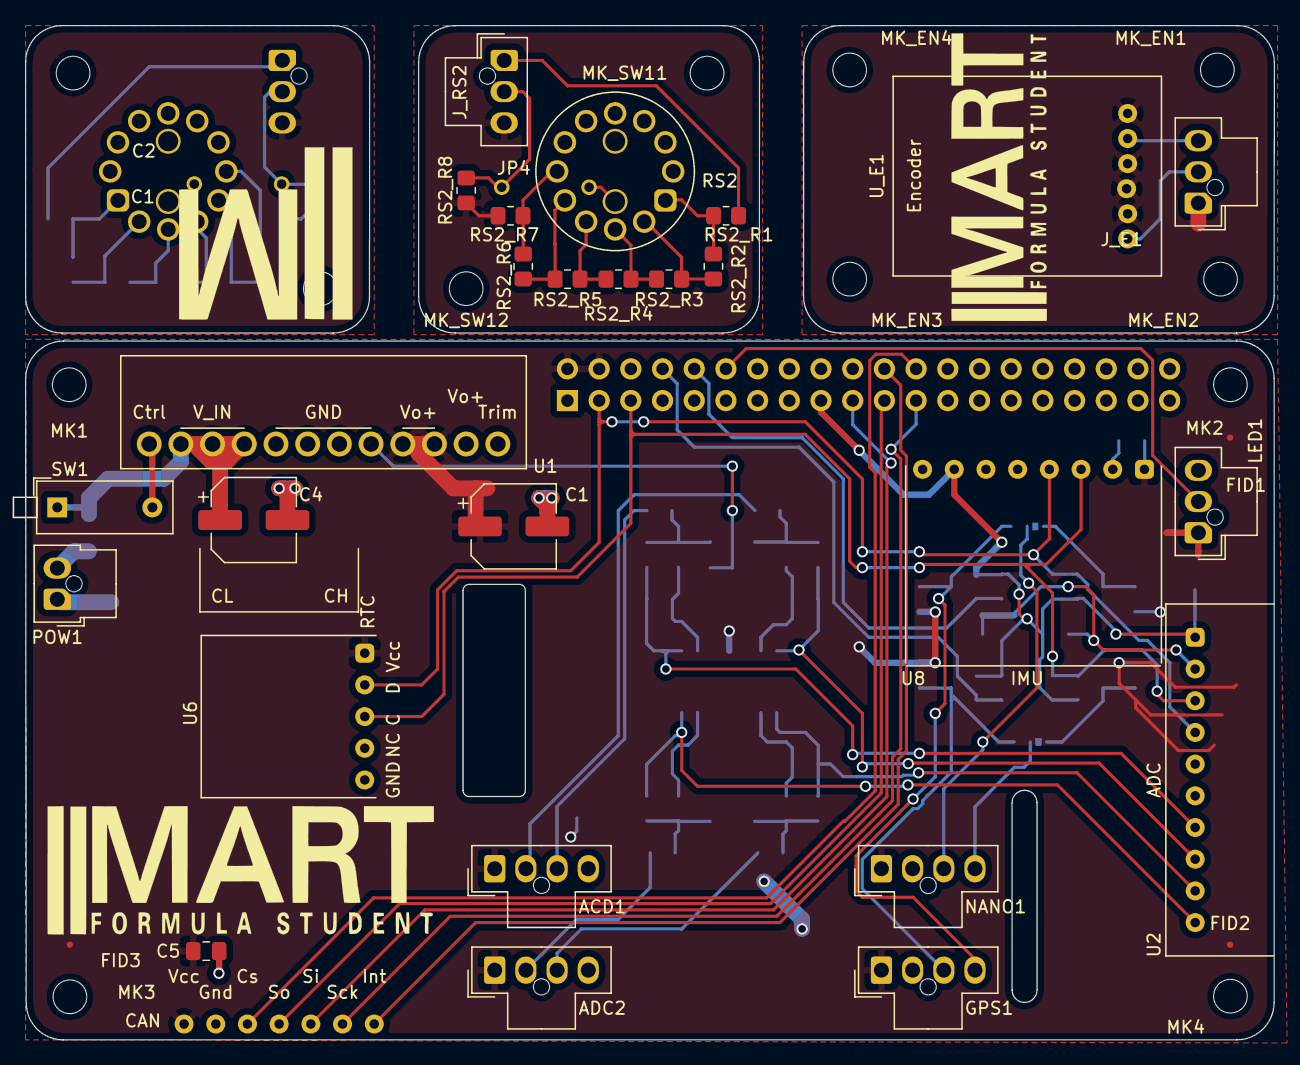
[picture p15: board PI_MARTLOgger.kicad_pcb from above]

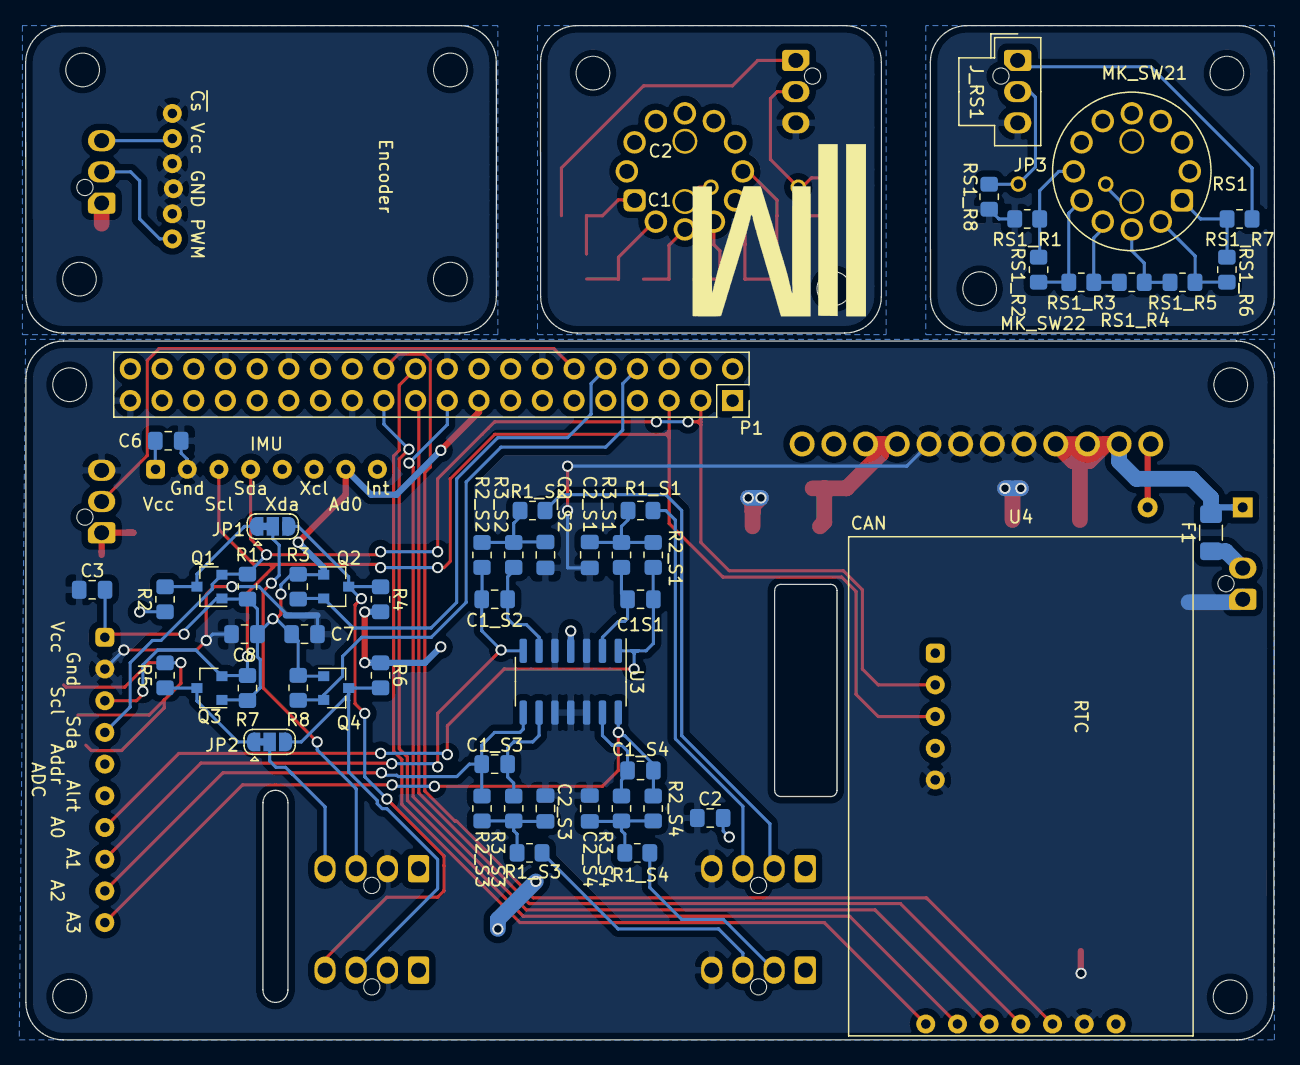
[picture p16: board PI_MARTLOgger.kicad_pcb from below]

Board: 2 copper layers, 100.1 x 81.3 mm, 96 parts (56 on the bottom side), 61 nets.

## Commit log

2021-02-04 Config_RPI first organization + RTC + I2C
2021-03-31 Flujos De prueba Can-Bus AD1115 NeoPixel, Data-Format CSV
2021-04-25 Add files via upload
    Cambios minimos (Prueba de funcionamiento del flujo en la segunda raspberry)
2021-04-28 Add files via upload
    Añadido marcha para poder verla y cambio entre dashboards
2021-04-28 Add files via upload
    subida de vd actualizada, la anterior no vale
2021-05-04 Add files via upload
    Actualización Dashboard, valor marcha centrado y template de temperatura sin terminar
2021-05-05 Add files via upload
    Marcha con RPM centrada en dashboard, datos de temperatura, presión de aceite,.. sin conseguir color de fondo para el datos
2021-05-09 Add files via upload
    Añadida foto logo mart en la primera pantalla, se han ajustado los tamaños de los tabs en la segunda pantalla
2021-05-16 Add files via upload
    Añadido color de fondo para rangos de valores de temperatura y presión de aceite
2021-06-11 Add KiCad Project
    [PCBs.sch, PI_MARTLOgger.kicad_pcb, PI_MARTLOgger.sch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]
2021-06-11 Add Matlab-Simscape Simulation ADC filter
2021-06-11 Add Schematics
2021-06-28 Schematics+Gerbers+KiCadFiles
    Update PiMART telemetry system
    [PCBs.sch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]
